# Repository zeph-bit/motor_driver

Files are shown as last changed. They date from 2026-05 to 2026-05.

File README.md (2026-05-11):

# motor_driver

A simple motor driver circuit designed to interface with an STM32F072 DISCOVERY board and a Pololu 37D, item /#2824, brushed DC motor.

The driver includes a current sense feature to monitor the motor output and a temperature monitoring feature.

Below are photos of the assembled motor driver.

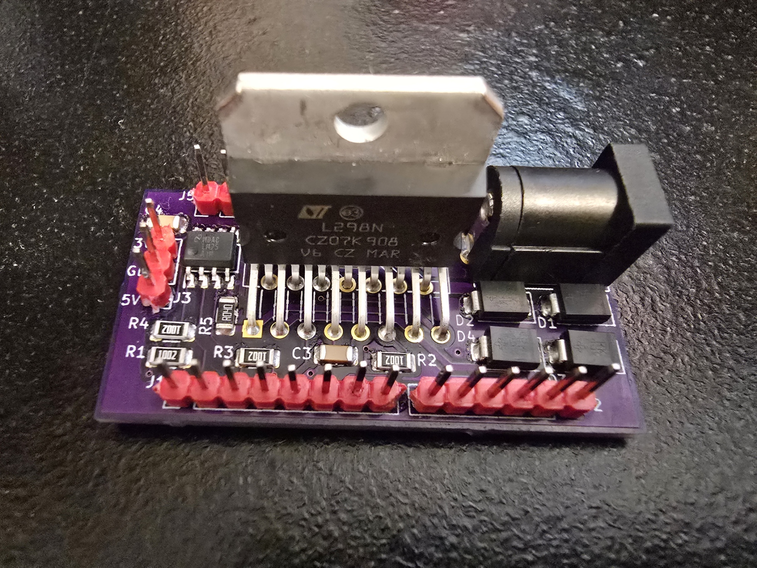
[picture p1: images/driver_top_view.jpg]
Motor Driver Top View

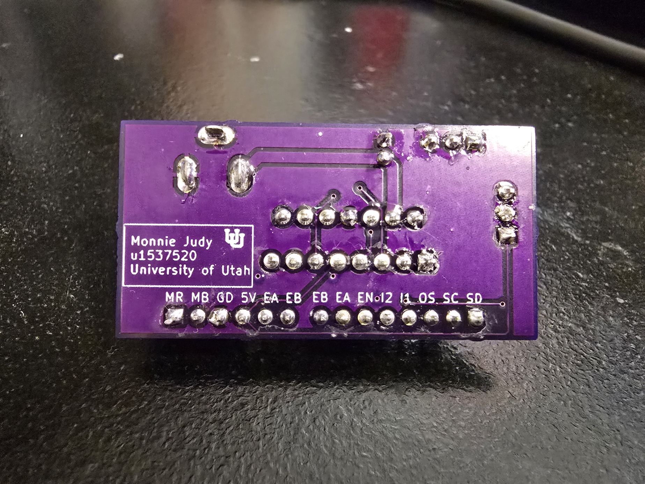
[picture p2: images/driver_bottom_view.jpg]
Motor Driver Bottom View


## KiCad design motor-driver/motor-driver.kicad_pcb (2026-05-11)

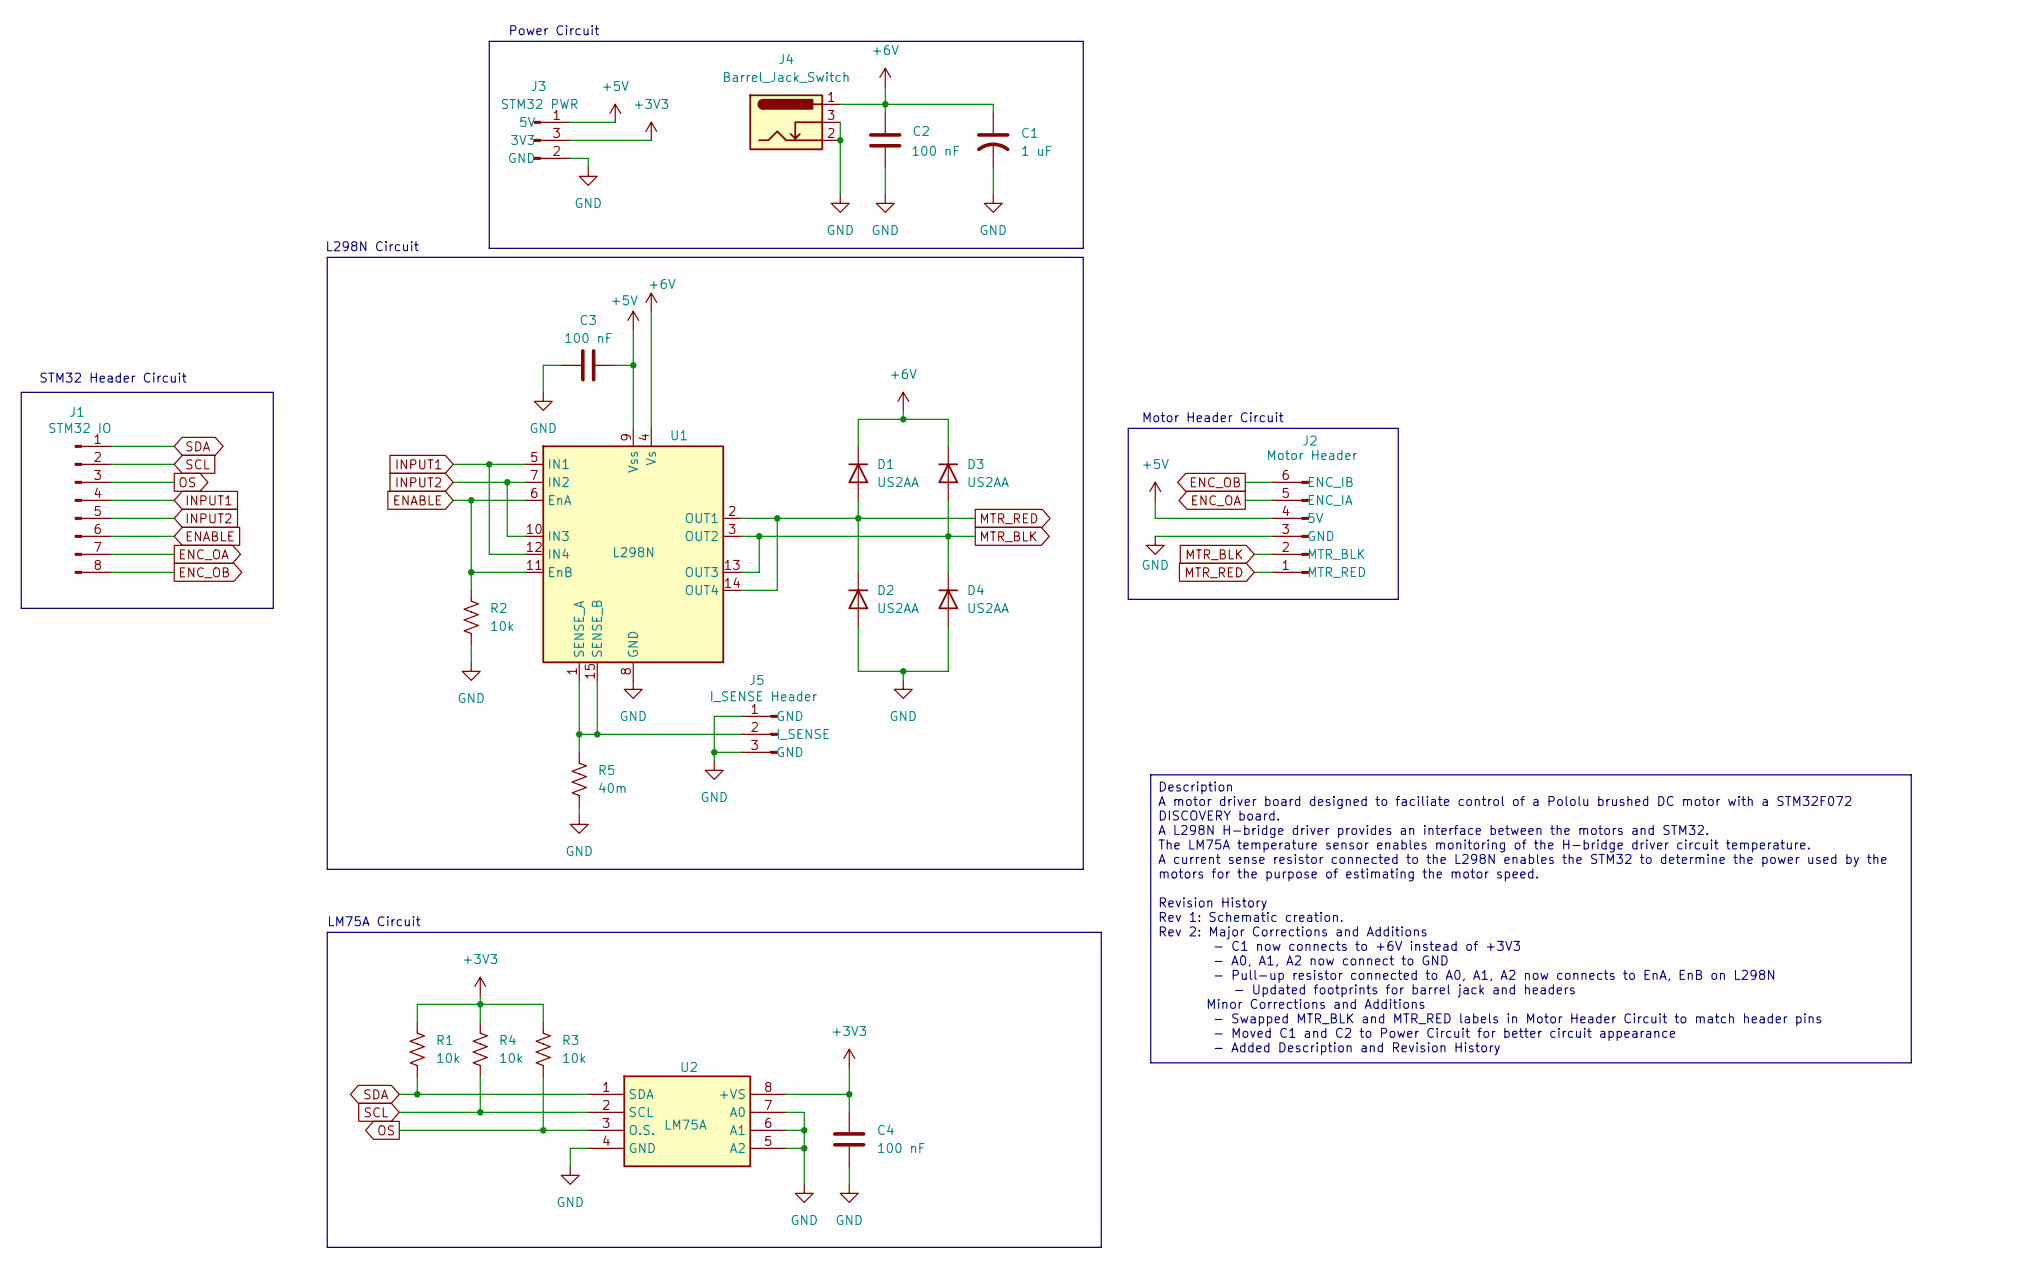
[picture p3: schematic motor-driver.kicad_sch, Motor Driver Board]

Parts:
C1: 1 uF; C_Radial_D5.0mm_H11.0mm_P2.00mm
C2, C3, C4: 100 nF; C_1206_3216Metric
D1, D2, D3, D4: US2AA; D_SMA
J1: STM32 IO; PinHeader_1x08_P2.54mm_Vertical
J2: Motor Header; PinHeader_1x06_P2.54mm_Vertical
J3: STM32 PWR; PinHeader_1x03_P2.54mm_Vertical
J4: Barrel_Jack_Switch; GRAVITECH_CON-SOCJ-2155
J5: I_SENSE Header; PinHeader_1x03_P2.54mm_Vertical
R1, R2, R3, R4: 10k; R_1206_3216Metric
R5: 40m; R_1206_3216Metric
U1: L298N; TO-220-15_P2.54x5.08mm_StaggerOdd_Lead4.58mm_Vertical
U2: LM75A; SOIC127P600X175-8N; Mouser Part Number 926-LM75AIMX/NOPB

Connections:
+3V3: C4.2, J3.3 (3V3), R1.1, R3.1, R4.1, U2.8 (+VS)
+5V: C3.2, J2.4 (5V), J3.1 (5V), U1.9 (Vss)
+6V: C1.1, C2.1, D1.1 (K), D3.1 (K), J4.1 (6V), U1.4 (Vs)
ENABLE: J1.6 (SCL), R2.1, U1.6 (EnA), U1.11 (EnB)
ENC_OA: J1.7 (ENC_OA), J2.5 (ENC_IA)
ENC_OB: J1.8 (ENC_OB), J2.6 (ENC_IB)
GND: C1.2, C2.2, C3.1, C4.1, D2.2 (A), D4.2 (A), J2.3 (GND), J3.2 (GND), J4.2, J4.3, J5.1 (GND), J5.3 (GND), R2.2, R5.2, U1.8 (GND), U2.4 (GND), U2.5 (A2), U2.6 (A1), U2.7 (A0)
INPUT1: J1.4 (OS), U1.5 (IN1), U1.12 (IN4)
INPUT2: J1.5 (SDA), U1.7 (IN2), U1.10 (IN3)
I_SENSE: J5.2 (I_SENSE), R5.1, U1.1 (SENSE_A), U1.15 (SENSE_B)
MTR_BLK: D3.2 (A), D4.1 (K), J2.2 (MTR_BLK), U1.3 (OUT2), U1.13 (OUT3)
MTR_RED: D1.2 (A), D2.1 (K), J2.1 (MTR_RED), U1.2 (OUT1), U1.14 (OUT4)
OS: J1.3 (ENABLE), R3.2, U2.3 (O.S.)
SCL: J1.2 (INPUT2), R4.2, U2.2 (SCL)
SDA: J1.1 (INPUT1), R1.2, U2.1 (SDA)

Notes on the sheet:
LM75A Circuit
L298N Circuit
Power Circuit
Motor Header Circuit
STM32 Header Circuit
Description A motor driver board designed to faciliate control of a Pololu brushed DC motor with a STM32F072 DISCOVERY board. A L298N H-bridge driver provides an interface between the motors and STM32. The LM75A temperature sensor enables monitoring of the H-bridge driver circuit temperature. A cur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

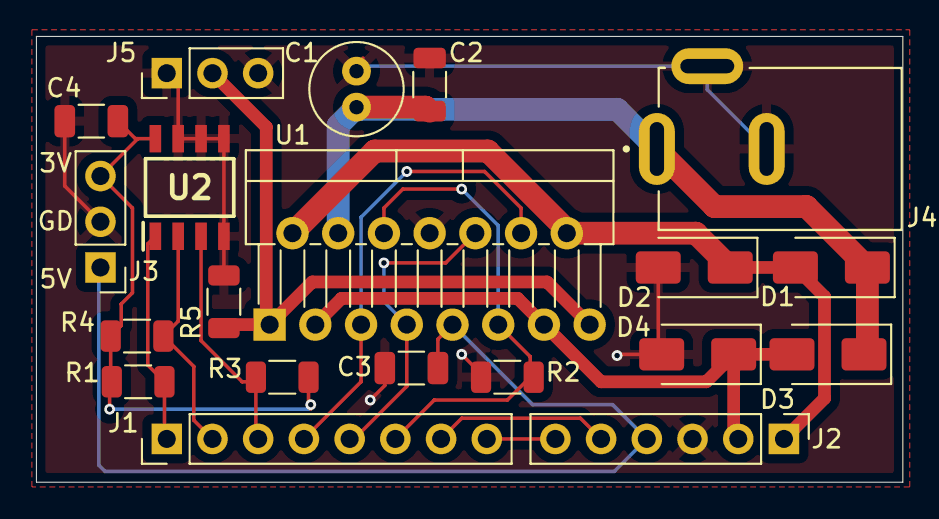
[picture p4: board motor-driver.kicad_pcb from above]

Board: 2 copper layers, 48.1 x 24.8 mm, 20 parts (0 on the bottom side), 15 nets.

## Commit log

2026-05-11 Adding motor driver circuit schematic and PCB layout files.
    [motor-driver-B_Paste.gbp, motor-driver-B_Paste.gbr, motor-driver-Edge_Cuts.gbr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]
2026-05-11 Updated README and added pphoto of assembled driver.
